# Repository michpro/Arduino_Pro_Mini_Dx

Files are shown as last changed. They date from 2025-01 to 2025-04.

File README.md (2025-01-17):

# **Arduino Pro Mini Dx Module**

- [**Arduino Pro Mini Dx Module**](#arduino-pro-mini-dx-module)
  - [**General info**](#general-info)
  - [**Hardware**](#hardware)
  - [**Software**](#software)
  - [**Reporting bugs**](#reporting-bugs)
  - [**License**](#license)
  - [**Support**](#support)

---

## **General info**
Through the use of the Arduino Pro Mini form factor PCB, this module allows easy replacement of modules based on the ATmega328P processor with modern solutions from the AVR Dx family. This allows a significant increase in program size (up to 128kB FLASH) and the use of many new peripherals.

---

## **Hardware**
The module dispenses with the use of an external high-frequency resonator. The clocking of the uC is generated by an internal RC resonator. It has sufficient accuracy for most applications, which can be further improved by internal calibration using the mounted RTC resonator (32768 Hz). This also allows the uC's clock frequency to be changed even during programme execution.<br>
A dedicated voltage regulator has also been dispensed with, as the uCs of the AVR Dx family operate stably over the full supply voltage range: 1.8-5.5V with a maximum clock frequency of 24MHz.<br><br>
Below is a schematic diagram:<br>
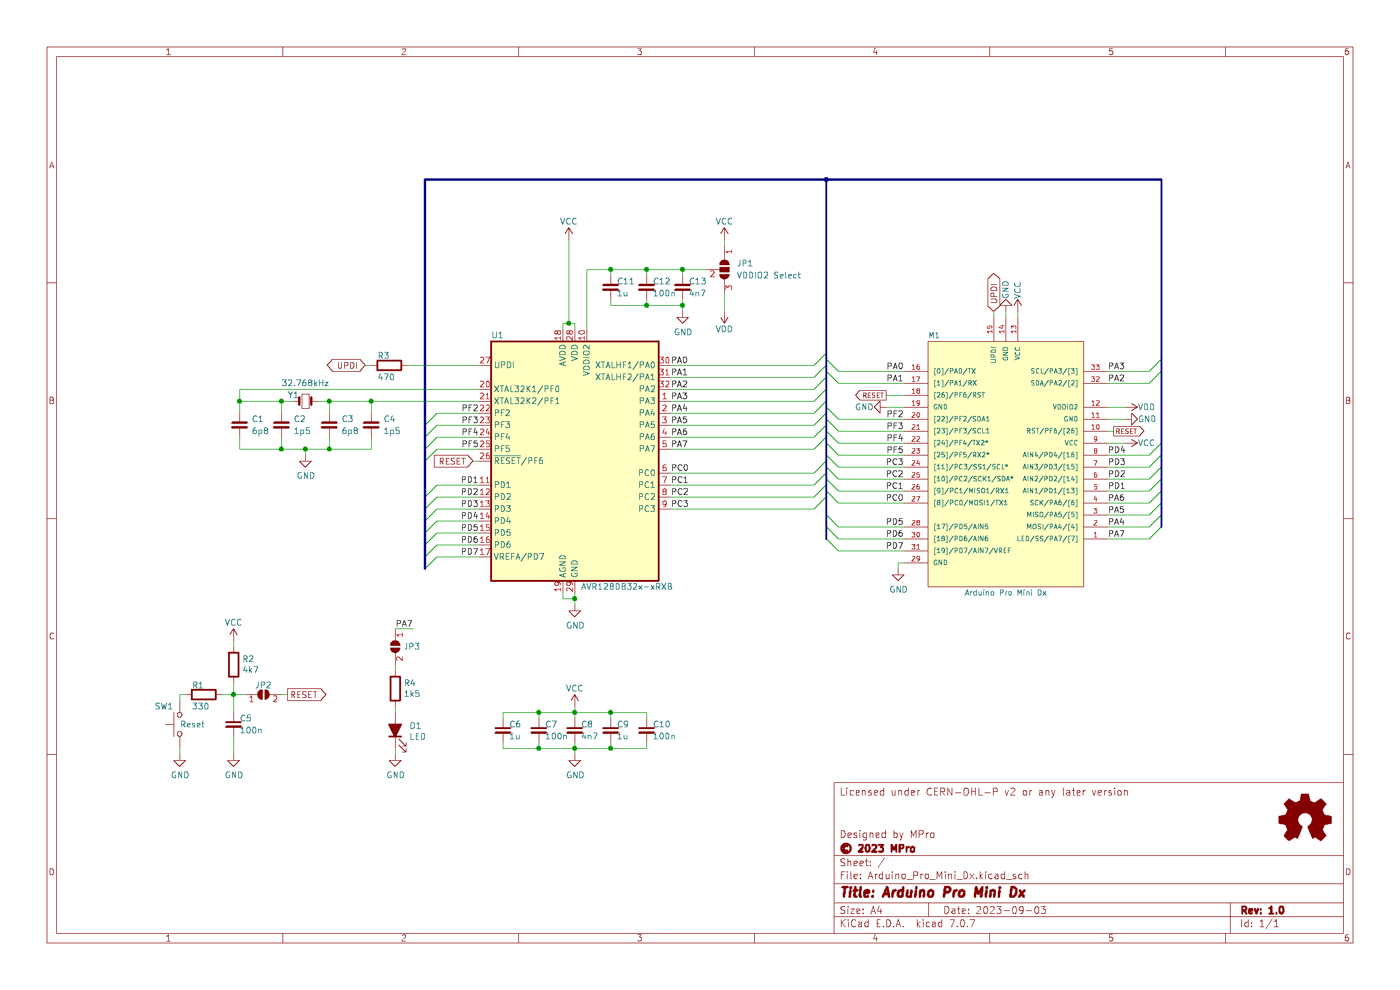
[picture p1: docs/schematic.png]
wiring diagram

<br>
and visualisation of the module (click picture):
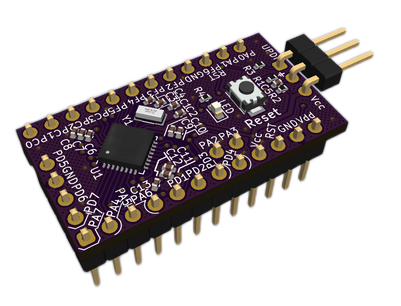
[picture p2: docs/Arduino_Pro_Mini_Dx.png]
Arduino Pro Mini Dx
<p align="center"></p>

The production files can be found in the location: https://github.com/michpro/Arduino_Pro_Mini_Dx/blob/master/production/

---

## **Software**
The module can be used with any toolchain:
 - Arduino, PlatformIO - [SpenceKonde - DxCore](https://github.com/SpenceKonde/DxCore)
 - or Microchip Studio for AVR®.

The program code is uploaded to the module using the [UPDI programmer](https://github.com/SpenceKonde/DxCore?tab=readme-ov-file#updi-programming).

---

## **Reporting bugs**

[Create an issue on GitHub](https://github.com/michpro/Arduino_Pro_Mini_Dx/issues).

---

## **License**
Copyright © 2023-2025 Michal Protasowicki

Source: https://github.com/michpro/Arduino_Pro_Mini_Dx

This project is released under CERN Open Hardware Licence Version 2 - Permissive.



---

## **Support**
If You find my projects interesting and You wanted to support my work, You can give me a cup of coffee or a keg of beer :)

&nbsp;&nbsp;&nbsp;&nbsp;&nbsp;&nbsp;&nbsp;&nbsp;&nbsp;&nbsp;

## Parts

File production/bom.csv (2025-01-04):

Designator | Footprint | Quantity | Value | LCSC Part #
C1, C3 | 0402 | 2 | 6p8 | C1576
C10, C12, C5, C7 | 0402 | 4 | 100n | C1525
C11, C6, C9 | 0402 | 3 | 1u | C52923
C13, C8 | 0402 | 2 | 4n7 | C1538
C2, C4 | 0402 | 2 | 1p5 | C1552
D1 | 0603 | 1 | LED | C2286
R1 | 0402 | 1 | 330 | C25104
R2 | 0402 | 1 | 4k7 | C25900
R3 | 0402 | 1 | 470 | C25117
R4 | 0402 | 1 | 1k5 | C25867
SW1 | TS-1088R-02526_SPST | 1 | Reset | C455281
U1 | QFN-32-1EP_5x5mm_P0.5mm_EP3.1x3.1mm | 1 | AVR128DB32x-xRXB | C1518641
Y1 | Crystal_SMD_3215-2Pin_3.2x1.5mm | 1 | 32.768kHz | C5830644

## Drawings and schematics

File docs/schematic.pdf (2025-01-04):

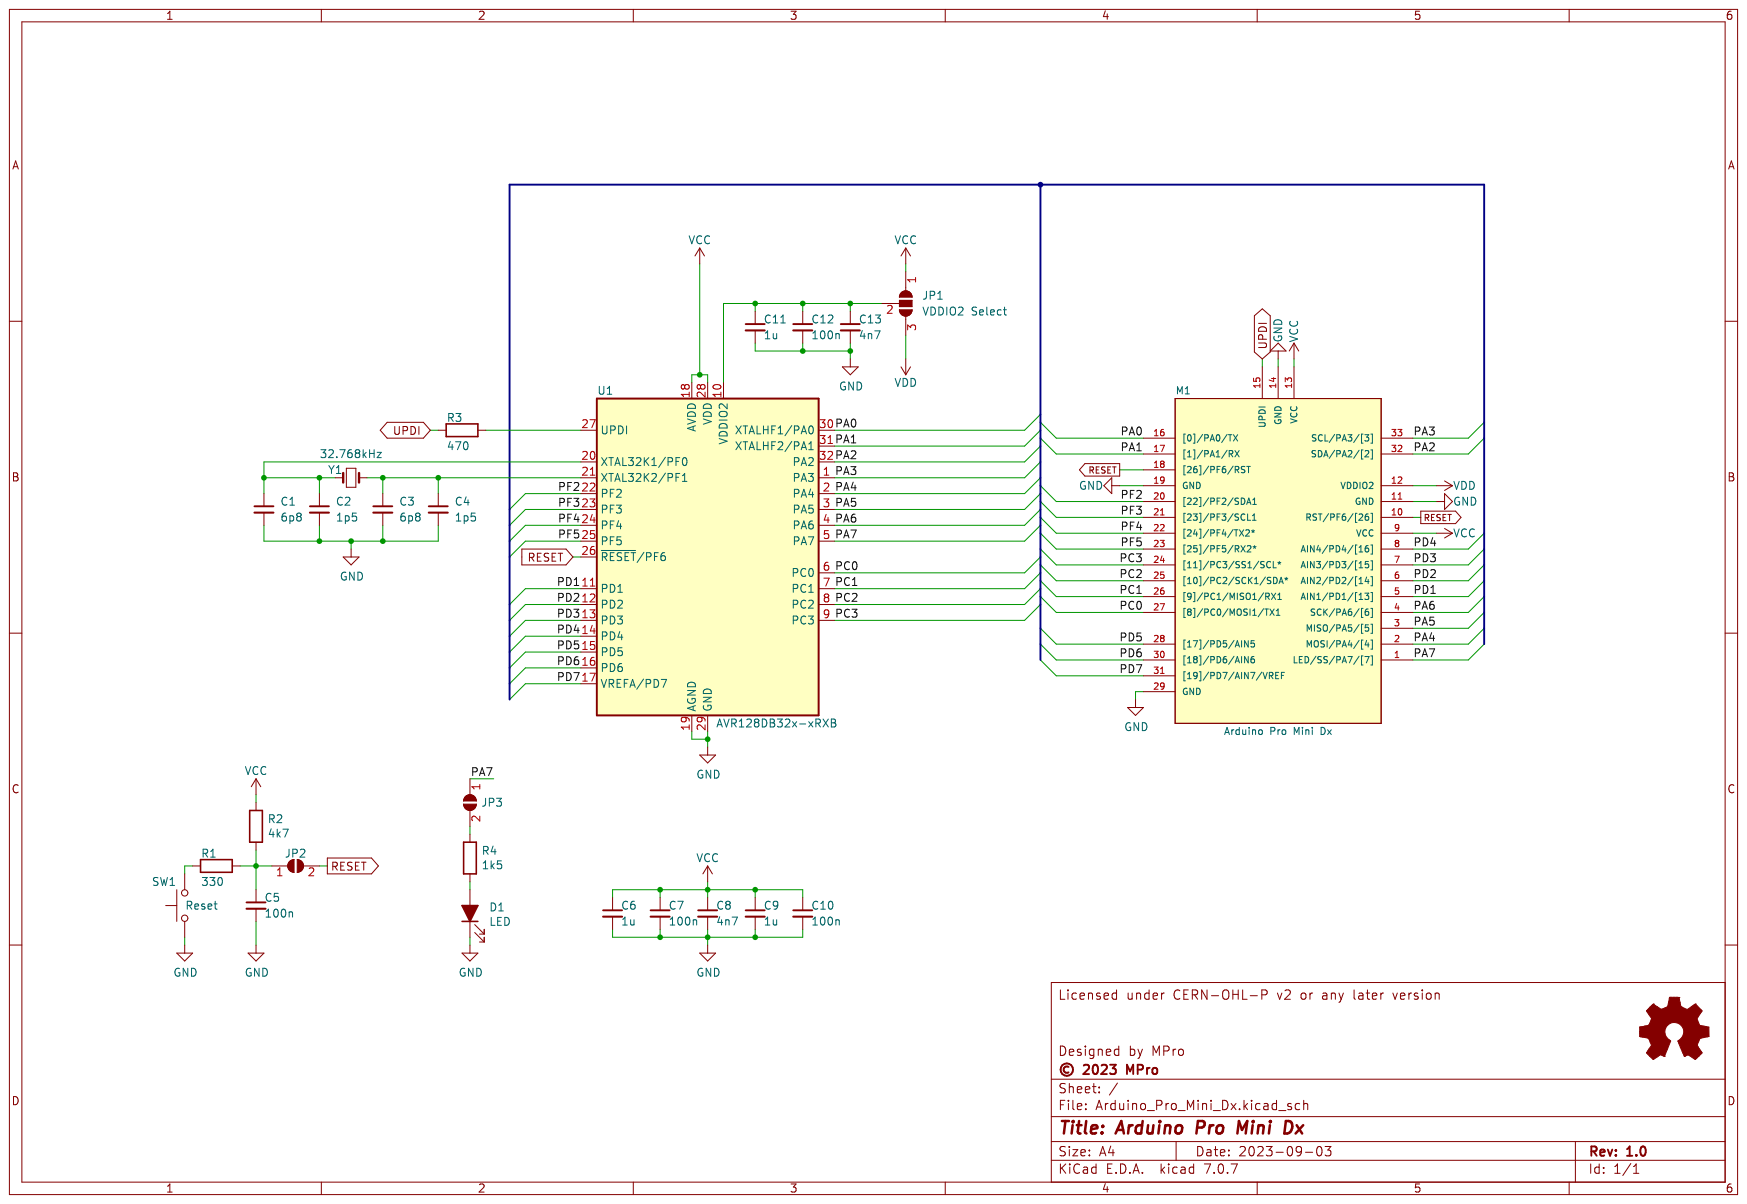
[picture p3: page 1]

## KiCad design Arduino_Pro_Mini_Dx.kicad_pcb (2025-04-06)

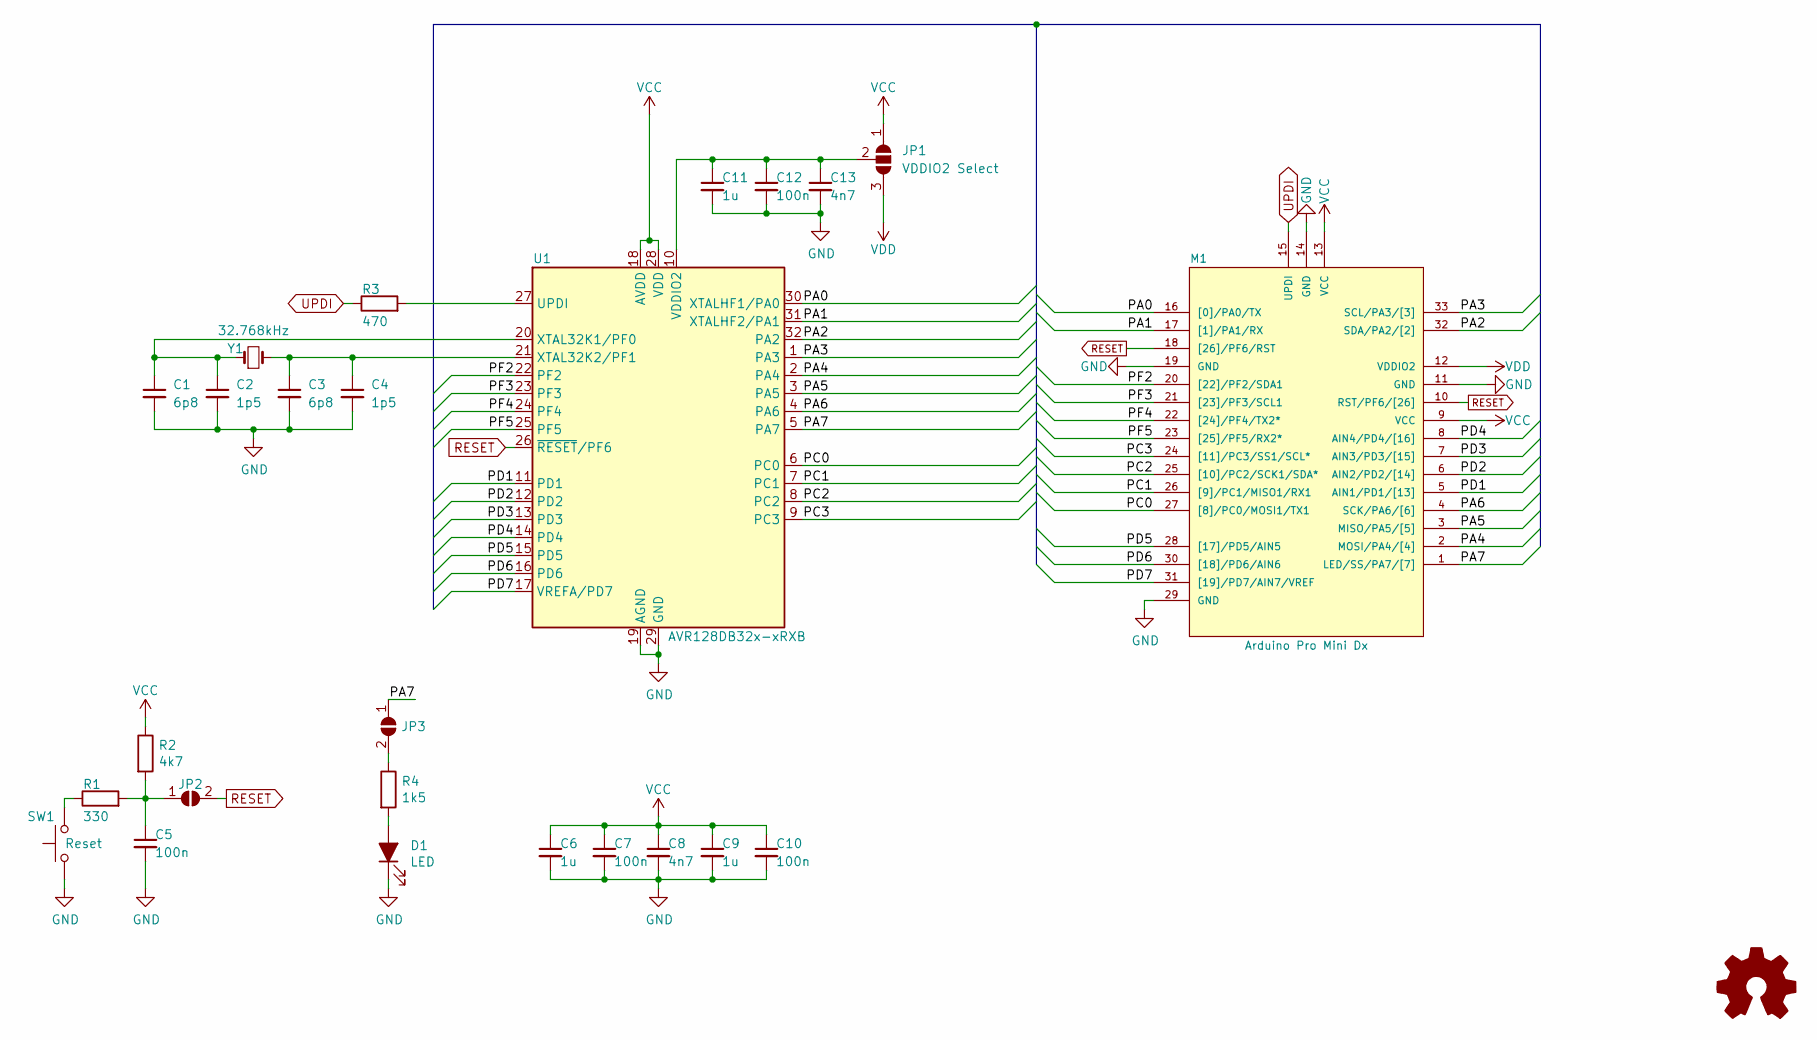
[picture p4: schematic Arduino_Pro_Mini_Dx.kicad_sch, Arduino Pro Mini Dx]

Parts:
C1, C3: 6p8; C_0402_1005Metric; LCSC C1576
C2, C4: 1p5; C_0402_1005Metric; LCSC C1552
C5, C7, C10, C12: 100n; C_0402_1005Metric; LCSC C1525
C6, C9, C11: 1u; C_0402_1005Metric; LCSC C52923
C8, C13: 4n7; C_0402_1005Metric; LCSC C1538
D1: LED; LED_0603_1608Metric; LCSC C2286
JP1: VDDIO2 Select; SolderJumper-3_P1.3mm_Open_RoundedPad1.0x1.5mm
JP2: RST; SolderJumper-2_P1.3mm_Open_TrianglePad1.0x1.5mm
JP3: LED; SolderJumper-2_P1.3mm_Open_TrianglePad1.0x1.5mm
LOGO1: Logo_Open_Hardware_Small; OSHW-Logo2_7.3x6mm_SilkScreen
M1: Arduino Pro Mini Dx; diy-modules-ARDUINO-PRO-MINI-Dx-BRD
R1: 330; R_0402_1005Metric; LCSC C25104
R2: 4k7; R_0402_1005Metric; LCSC C25900
R3: 470; R_0402_1005Metric; LCSC C25117
R4: 1k5; R_0402_1005Metric; LCSC C25867
SW1: Reset; TS-1088R-02526_SPST; LCSC C455281
U1: AVR128DB32x-xRXB; QFN-32-1EP_5x5mm_P0.5mm_EP3.1x3.1mm; LCSC C1518641
Y1: 32.768kHz; Crystal_SMD_3215-2Pin_3.2x1.5mm; LCSC C5830644

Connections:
/PA0: M1.16 ([0]/PA0/TX), U1.30 (XTALHF1/PA0)
/PA1: M1.17 ([1]/PA1/RX), U1.31 (XTALHF2/PA1)
/PA2: M1.32 (SDA/PA2/[2]), U1.32 (PA2)
/PA3: M1.33 (SCL/PA3/[3]), U1.1 (PA3)
/PA4: M1.2 (MOSI/PA4/[4]), U1.2 (PA4)
/PA5: M1.3 (MISO/PA5/[5]), U1.3 (PA5)
/PA6: M1.4 (SCK/PA6/[6]), U1.4 (PA6)
/PA7: JP3.1 (A), M1.1 (LED/SS/PA7/[7]), U1.5 (PA7)
/PC0: M1.27 ([8]/PC0/MOSI1/TX1), U1.6 (PC0)
/PC1: M1.26 ([9]/PC1/MISO1/RX1), U1.7 (PC1)
/PC2: M1.25 ([10]/PC2/SCK1/SDA*), U1.8 (PC2)
/PC3: M1.24 ([11]/PC3/SS1/SCL*), U1.9 (PC3)
/PD1: M1.5 (AIN1/PD1/[13]), U1.11 (PD1)
/PD2: M1.6 (AIN2/PD2/[14]), U1.12 (PD2)
/PD3: M1.7 (AIN3/PD3/[15]), U1.13 (PD3)
/PD4: M1.8 (AIN4/PD4/[16]), U1.14 (PD4)
/PD5: M1.28 ([17]/PD5/AIN5), U1.15 (PD5)
/PD6: M1.30 ([18]/PD6/AIN6), U1.16 (PD6)
/PD7: M1.31 ([19]/PD7/AIN7/VREF), U1.17 (VREFA/PD7)
/PF2: M1.20 ([22]/PF2/SDA1), U1.22 (PF2)
/PF3: M1.21 ([23]/PF3/SCL1), U1.23 (PF3)
/PF4: M1.22 ([24]/PF4/TX2*), U1.24 (PF4)
/PF5: M1.23 ([25]/PF5/RX2*), U1.25 (PF5)
GND: C1.2, C2.2, C3.2, C4.2, C5.2, C6.2, C7.2, C8.2, C9.2, C10.2, C11.2, C12.2, C13.2, D1.1 (K), M1.11 (GND), M1.14 (GND), M1.19 (GND), M1.29 (GND), SW1.1, U1.19 (AGND), U1.29 (GND), U1.33 (GND)
unnamed: D1.2 (A), R4.2
unnamed: C11.1, C12.1, C13.1, JP1.2 (C), U1.10 (VDDIO2)
unnamed: C5.1, JP2.1 (A), R1.2, R2.2
unnamed: JP3.2 (B), R4.1
unnamed: R1.1, SW1.2
unnamed: R3.2, U1.27 (UPDI)
unnamed: C1.1, C2.1, U1.20 (XTAL32K1/PF0), Y1.1
unnamed: C3.1, C4.1, U1.21 (XTAL32K2/PF1), Y1.2
RESET: JP2.2 (B), M1.10 (RST/PF6/[26]), M1.18 ([26]/PF6/RST), U1.26 (~RESET/PF6)
UPDI: M1.15 (UPDI), R3.1
VCC: C6.1, C7.1, C8.1, C9.1, C10.1, JP1.1 (A), M1.9 (VCC), M1.13 (VCC), R2.1, U1.18 (AVDD), U1.28 (VDD)
VDD: JP1.3 (B), M1.12 (VDDIO2)

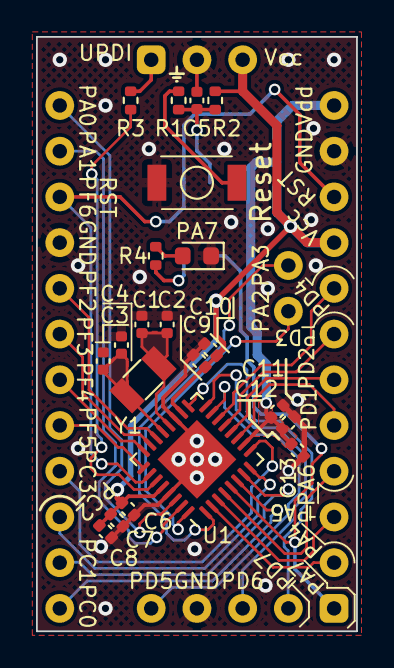
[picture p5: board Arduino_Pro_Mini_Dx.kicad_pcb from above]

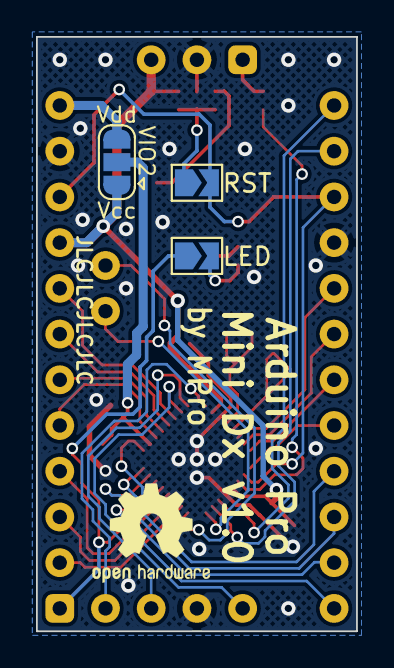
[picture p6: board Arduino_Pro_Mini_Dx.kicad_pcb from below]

Board: 2 copper layers, 17.8 x 33.0 mm, 26 parts (4 on the bottom side), 36 nets.

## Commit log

2025-01-04 functional revision
    [Arduino_Pro_Mini_Dx.kicad_pcb, Arduino_Pro_Mini_Dx.kicad_sch, bom.csv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]
2025-04-06 project files updated to Kicad version 9.0.1
    [Arduino_Pro_Mini_Dx.kicad_pcb, Arduino_Pro_Mini_Dx.kicad_sch]

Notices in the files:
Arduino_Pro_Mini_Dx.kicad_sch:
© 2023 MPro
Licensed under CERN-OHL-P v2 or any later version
